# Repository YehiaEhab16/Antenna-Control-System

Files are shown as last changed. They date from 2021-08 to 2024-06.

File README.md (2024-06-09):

# Antenna-Control-System

Using Arduino, an antenna is controlled to keep track of a satellite during 4 sessions daily.
The system is used to control the antenna using 2 speeds and in 2 directions

## <a href="https://github.com/AhmedAbo-zeid" target="_blank">Ahmed AboZeid</a>
## Mario Abdelmeseeh
## Mohamed Abdelmegeed
## <a href="https://github.com/Tarek9100" target="_blank">Tarek Wael</a>
## <a href="https://github.com/yehia2000000" target="_blank">Yehia Shahin</a>
## <a href="https://github.com/YehiaEhab16" target="_blank">Yehia Ehab</a>

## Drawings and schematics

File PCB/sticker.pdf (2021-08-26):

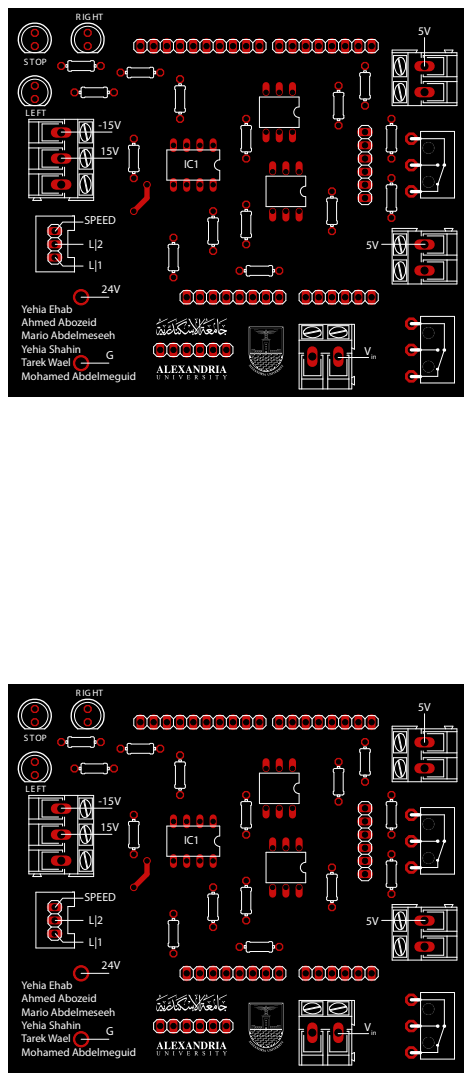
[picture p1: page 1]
S TOP; Vin; SPEED; Yehia Ehab Ahmed Abozeid Mario Abdelmeseeh Yehia Shahin Tarek Wael Mohamed Abdelmeguid

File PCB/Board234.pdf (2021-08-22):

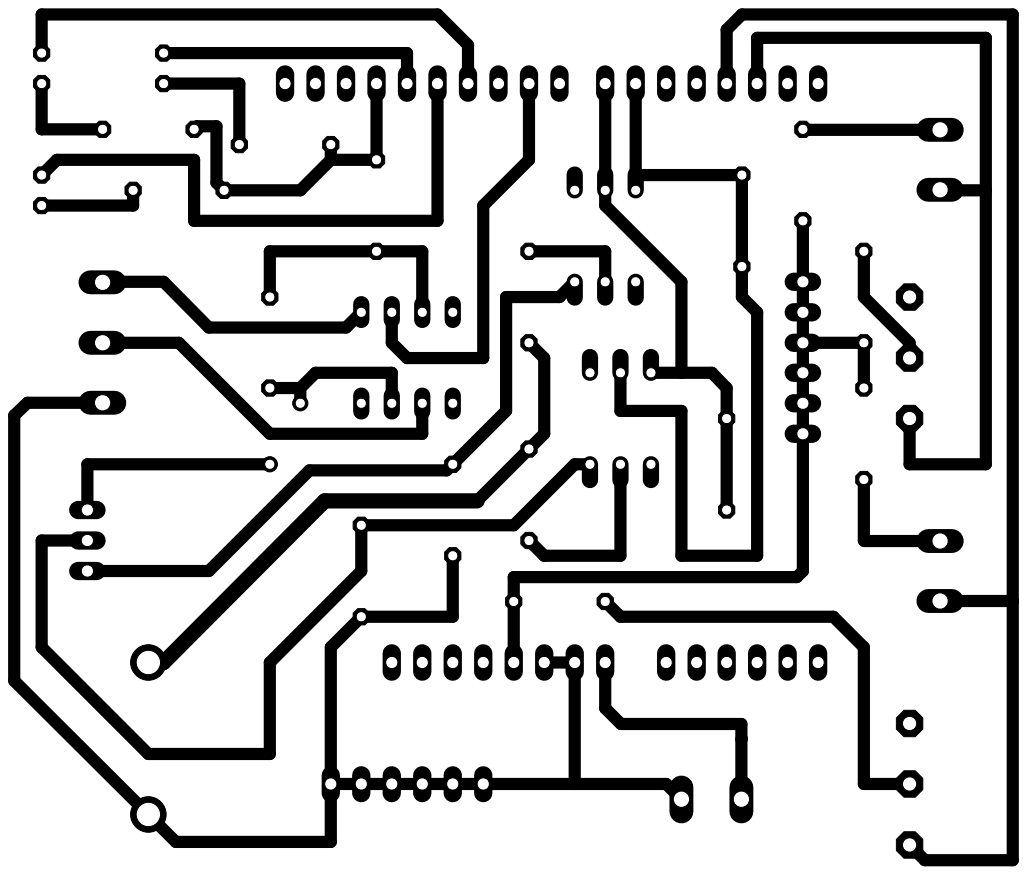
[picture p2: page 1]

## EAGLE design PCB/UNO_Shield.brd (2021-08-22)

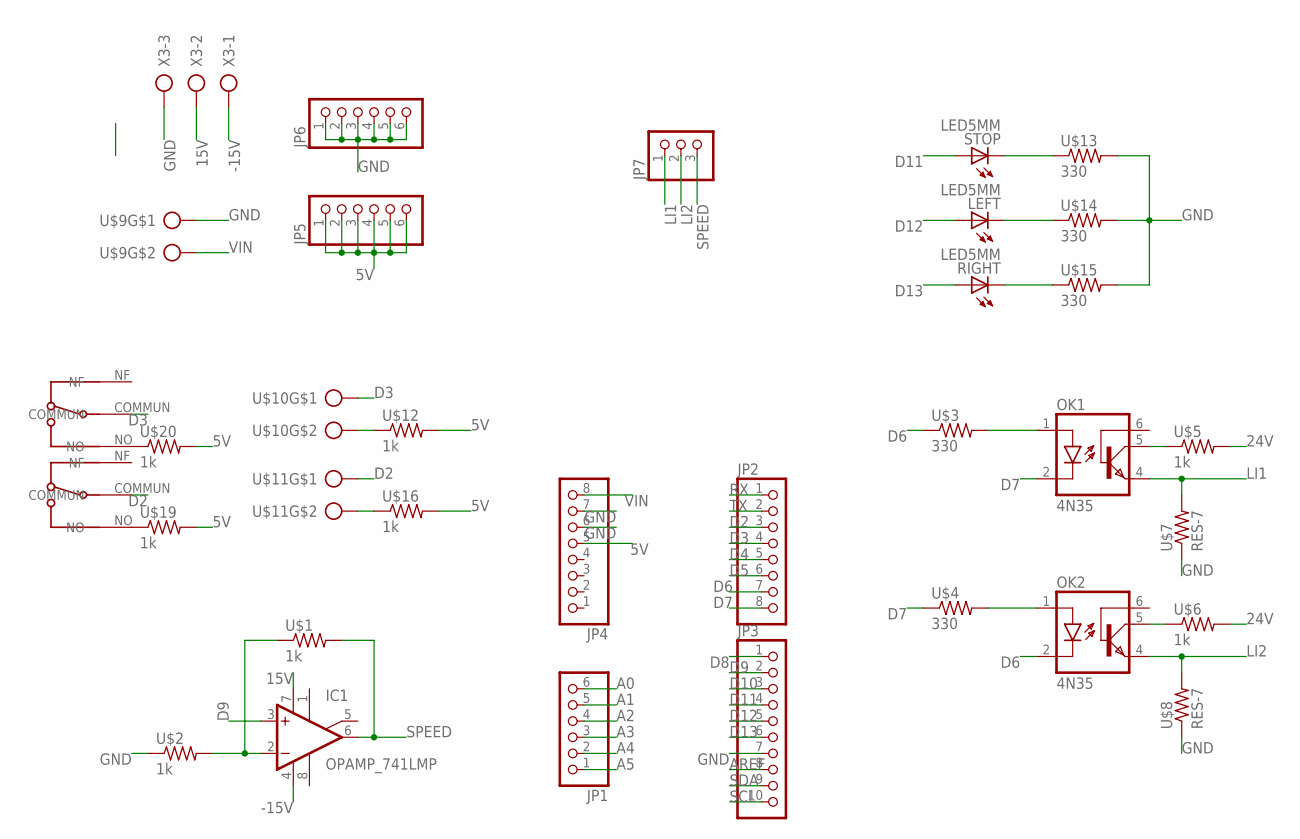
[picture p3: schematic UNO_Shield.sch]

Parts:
IC1: OPAMP_741LMP; DIL08
JP1, JP5, JP6: PINHD-1X6; 1X06
JP2, JP4: PINHD-1X8; 1X08
JP3: PINHD-1X10; 1X10
JP7: PINHD-3_DATA; 1X03_DATA
LEFT: LED5MM
OK1, OK2: 4N35; DIL06
RIGHT: LED5MM
STOP: LED5MM
U$1, U$2, U$5, U$6, U$12, U$16, U$19, U$20: 1k; 0204/7
U$3, U$4, U$13, U$14, U$15: 330; 0204/7
U$7, U$8: RES-7; 0204/7
U$9, U$10, U$11: CON_PTR_2; AK300/2
U$17, U$18: MICROSWITCHCOUDE; DG23-B3RA
X3: CON_PTR_3; AK300/3

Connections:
5V: JP4.5, JP5.1, JP5.2, JP5.3, JP5.4, JP5.5, JP5.6, U$12.2, U$16.2, U$19.2, U$20.2
15V: IC1.7 (V+), X3.2
24V: U$5.2, U$6.2
-15V: IC1.4 (V-), X3.1
A0: JP1.6
A1: JP1.5
A2: JP1.4
A3: JP1.3
A4: JP1.2
A5: JP1.1
AREF: JP3.8
D2: JP2.3, U$11.1, U$18.COMMUN
D3: JP2.4, U$10.1, U$17.COMMUN
D4: JP2.5
D5: JP2.6
D6: JP2.7, OK1.1 (A), OK2.2 (C), U$3.1, U$3.2
D7: JP2.8, OK1.2 (C), OK2.1 (A), U$4.1, U$4.2
D8: JP3.1
D9: IC1.3 (+IN), JP3.2
D10: JP3.3
D11: JP3.4, STOP.A
D12: JP3.5, LEFT.A
D13: JP3.6, RIGHT.A
GND: JP3.7, JP4.6, JP4.7, JP6.1, JP6.2, JP6.3, JP6.4, JP6.5, JP6.6, U$2.1, U$7.1, U$8.1, U$9.1, U$13.2, U$14.2, U$15.2, X3.3
LI1: JP7.1, OK1.4 (EMI), U$7.2
LI2: JP7.2, OK2.4 (EMI), U$8.2
unnamed: IC1.2 (-IN), U$1.1, U$2.2
unnamed: OK1.5 (COL), U$5.1
unnamed: U$10.2, U$12.1
unnamed: STOP.K (C), U$13.1
unnamed: U$11.2, U$16.1
unnamed: U$18.NO, U$19.1
unnamed: U$17.NO, U$20.1
unnamed: LEFT.K (C), U$14.1
unnamed: OK2.5 (COL), U$6.1
unnamed: RIGHT.K (C), U$15.1
RX: JP2.1
SCL: JP3.10
SDA: JP3.9
SPEED: IC1.6 (OUT), JP7.3, U$1.2
TX: JP2.2
VIN: JP4.8, U$9.2

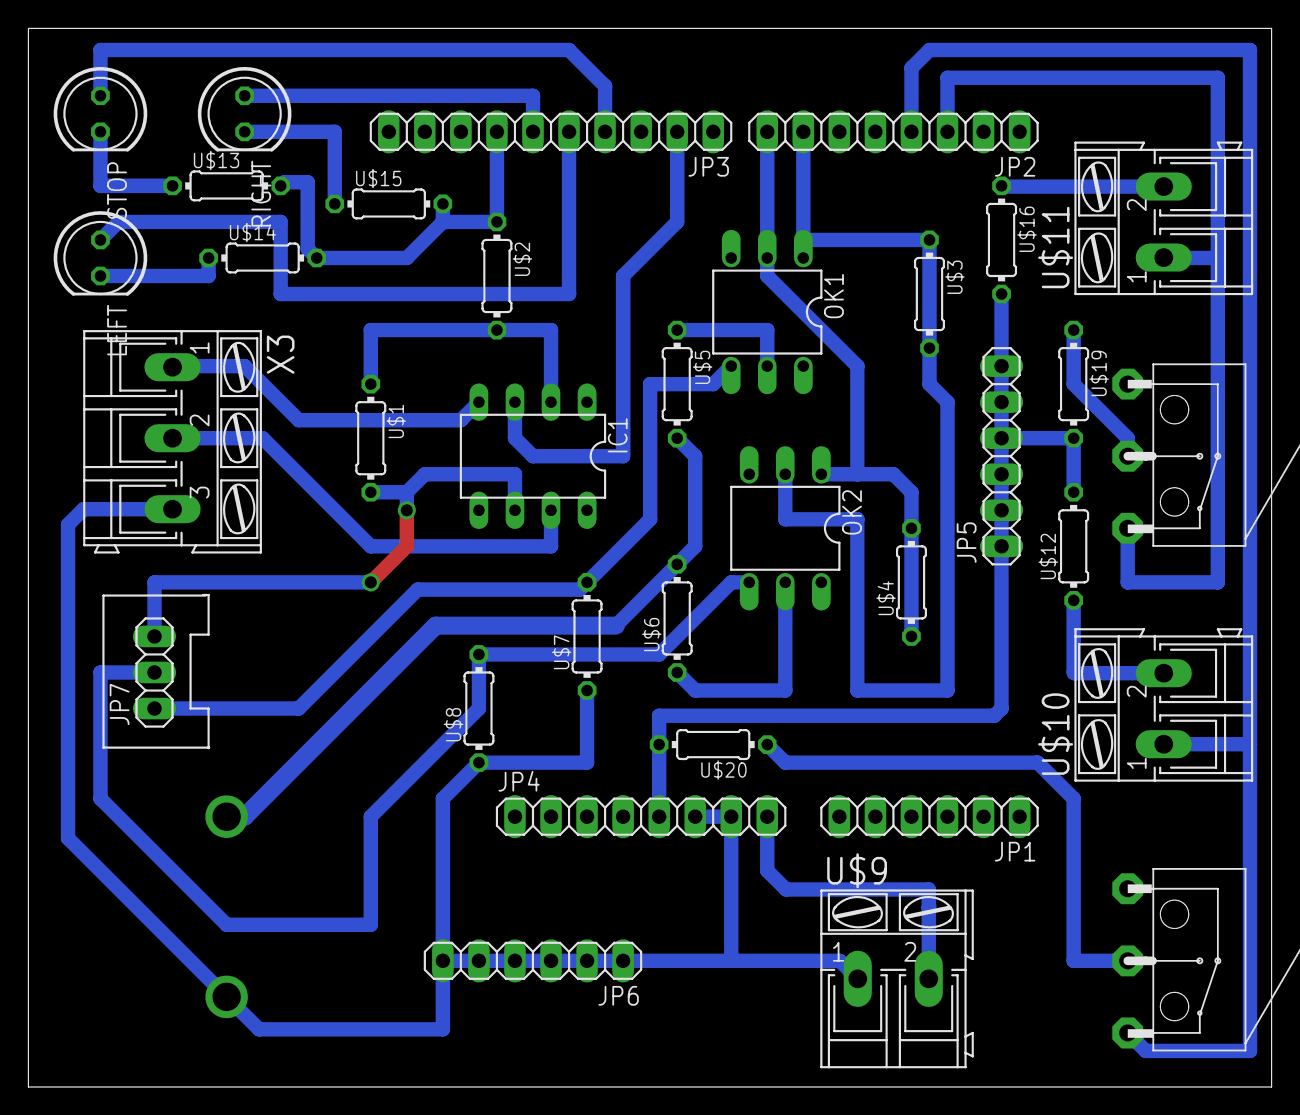
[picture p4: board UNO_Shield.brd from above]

Board: 2 copper layers, 87.6 x 74.6 mm, 34 parts (0 on the bottom side), 27 nets.

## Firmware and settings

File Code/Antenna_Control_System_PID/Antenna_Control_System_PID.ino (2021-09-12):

#include <SoftwareSerial.h>         //Including SoftwareSerial library to connect with bluetooth module
#include "Modules.h"                //Including the defined library 'Modules'
#include "PID_v1.h"                 //Including the defined library 'PID_v1.h'

//Define Variables we'll be connecting to
double DesiredAngle=0, CurrentAngle=0,DiffAngle;
volatile double Output;

//Specify the links and initial tuning parameters
double Kp=2, Ki=0, Kd=0.1;

//Creating object from PID library
PID myPID(&CurrentAngle, &Output, &DesiredAngle, Kp, Ki, Kd, DIRECT);

//Bluetooth module for Mobile Application
SoftwareSerial mySerial(RX, TX);

//Declaration of global variables
String inputString = "";        //Variable that holds the recieved string
bool stringComplete = false,PID_flag=false;    //Flag to indicate recieving of string from application or LabView

//ISRs for external interrupt
void Min_Limit_Reached();
void Max_Limit_Reached();

void setup() {
  //Initalizing needed pins as output
  Init();

  //Attaching interrupts at pins 0&1
  attachInterrupt(INTERRUPT_ID1,Min_Limit_Reached,RISING);
  attachInterrupt(INTERRUPT_ID2,Max_Limit_Reached,RISING);

  //Initalizing software serial connection
  mySerial.begin(9600);
  myPID.SetMode(AUTOMATIC);   //Turning on PID
  myPID.SetOutputLimits(Calculate_Speed(MIN_VOLTAGE), Calculate_Speed(MAX_VOLTAGE));  //Setting Limits for the output
}

void loop() {
  //Checking data from applcation
   if(mySerial.available())
  {
    inputString=mySerial.readString();
    stringComplete=true;  //Flag to indicate the completion of the string
  }
  if (stringComplete) //Checking for flag
  {
    DesiredAngle = inputString.toInt();     //Converting to integer
    inputString = "";                       //Clearing string
    stringComplete = false;                 //Clearing Flag
    PID_flag=true;                          //Setting flag to enter loop
    while(PID_flag==true)
    {
      CurrentAngle = Encoder_Read();            //Updating current angle using encoder
      DiffAngle = DesiredAngle - CurrentAngle;
      //Determining direction according to the difference
      if(DiffAngle>0)
      {
        Forward();
      }
      else if(DiffAngle<0)
      {
        Backward();
      }
      myPID.Compute();                          //Calculating error to determine output using PID
      Motor_SetSpeed(abs(Output));  //Setting mootor speed according to calculated output
      Serial_Print(CurrentAngle, DiffAngle, Output);
      if(abs(Output)==0)
      {
        LED_Stop();
        PID_flag=false;
      }
    }
  }
}

//For read from write buffer
void serialEvent() 
{
  while (Serial.available()) {
    char inChar = (char)Serial.read();   //Reading character from serial
    if (inChar == '#')                   //Checking for stop bit '#'
    {
      stringComplete = true;             //Setting flag to indicate recieving of string
    }
    if(!stringComplete)
      inputString += inChar;            //Concatenating string until reaching full message
  }
}

//ISR when reaching minimum limit
void Min_Limit_Reached()
{
  Serial.println("Min Interrupt");
  Motor_Stop();
  LED_Stop();
  Output=0;
  CurrentAngle=MIN_ANGLE;
  PID_flag=false;
}
//ISR when reaching maximum limit
void Max_Limit_Reached()
{
  Serial.println("Max Interrupt");
  Motor_Stop();
  LED_Stop();
  Output=0;
  CurrentAngle=MAX_ANGLE;
  PID_flag=false;
}

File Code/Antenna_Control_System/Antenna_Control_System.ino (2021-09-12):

#include <SoftwareSerial.h>         //Including SoftwareSerial library to connect with bluetooth module
#include "Modules.h"                //Including the defined library 'Modules'

//Bluetooth module for Mobile Application
SoftwareSerial mySerial(RX, TX);

//Declaration of global variables
int CurrentAngle=0,DesiredAngle,TotalTime=0,FinalAngle=0;
volatile int DiffAngle,Speed,Time;
String inputString = "";        //Variable that holds the recieved string
bool stringComplete = false,dir_flag=FORWARD,speed_flag=LOW_SPEED_OP,src_flag=APP;    //Flag to indicate recieving of string from application or LabView

//ISRs for external interrupt
void Min_Limit_Reached();
void Max_Limit_Reached();

void setup() 
{
  //Initaliziation
   Init();

   //Initalizing software serial connection
   mySerial.begin(9600);  

   //Attaching interrupts at pins 0&1
   attachInterrupt(INTERRUPT_ID1,Min_Limit_Reached,RISING);
   attachInterrupt(INTERRUPT_ID2,Max_Limit_Reached,RISING);
}

void loop() {
  //Checking data from applcation
   while(mySerial.available())
  {
    inputString=mySerial.readString();
    src_flag=APP;         //Flag to indicate that the sender is mobile application 
    stringComplete=true;  //Flag to indicate the completion of the string
  }
  if (stringComplete) //Checking for flag
  {
    DesiredAngle = inputString.toInt();     //Converting to integer
    inputString = "";                       //Clearing string
    stringComplete = false;                 //Clearing Flag
    DiffAngle = DesiredAngle - CurrentAngle;//Calculating difference between desired and current angle
    FinalAngle=DiffAngle;                    //Angle to be sended to labview

    //Determining direction according to the difference
    if(DiffAngle>0)
    {
      Forward(&dir_flag);
    }
    else if(DiffAngle<0)
    {
      Backward(&dir_flag);
    }
      
    //Determining speed according to the difference
    //Case1: Low speed operation
    if((abs(DiffAngle)<THRESHOLD_ANGLE)&&(abs(DiffAngle)>0))
    {
      Low_Speed_Op(&TotalTime,&speed_flag,DiffAngle);
    }
    //Case2: High speed operation
    else if(abs(DiffAngle)>THRESHOLD_ANGLE)
    {
      //The motor will first start at low speed for 5 degrees ,then it will continue with high speed until it reaches the last 5 degrees which will also be in low speed
      //Low speed interval
      speed_flag=HIGH_SPEED_OP;
      if(DiffAngle!=0)
      {
        Slow_Down(&TotalTime);
      }

      //High speed interval
      if(DiffAngle!=0)
      {
        High_Speed_Op(&TotalTime,DiffAngle);
      }

      //Low speed interval
      if(DiffAngle!=0)
      {
        Slow_Down(&TotalTime);
        Stop();
      }
    }
    if(DiffAngle!=0)
    {
      Serial_Print(&TotalTime,FinalAngle,src_flag,dir_flag,speed_flag);   //Sending all data to labview to be printed
    }
    CurrentAngle=DesiredAngle;    //Updating current angle after reaching desired position
  }
}

//For read from write buffer
void serialEvent() 
{
  while (Serial.available()) {
    char inChar = (char)Serial.read();   //Reading character from serial
    if (inChar == '#')                   //Checking for stop bit '#'
    {
      src_flag=GUI;                      //Flag to indicate that the sender is labview
      stringComplete = true;             //Setting flag to indicate recieving of string
    }
    if(!stringComplete)
      inputString += inChar;            //Concatenating string until reaching full message
  }
}

//ISR when reaching minimum limit
void Min_Limit_Reached()
{
  Serial.println("Min Interrupt, Angle=-168");
  Stop();
  Serial.println("STOP MOTOR");
  DiffAngle=0;
  Speed=0;
  Time=0;
  DesiredAngle=MIN_ANGLE;
}
//ISR when reaching maximum limit
void Max_Limit_Reached()
{
  Serial.println("Max Interrupt, Angle=168");
  Stop();
  Serial.println("STOP MOTOR");
  DiffAngle=0;
  Speed=0;
  Time=0;
  DesiredAngle=MAX_ANGLE;
}
